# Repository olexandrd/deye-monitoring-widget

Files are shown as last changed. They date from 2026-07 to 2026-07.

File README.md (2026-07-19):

# ESP32-C3 Deye Local Monitor

Embedded MVP for an ESP32-C3 SuperMini USB-C with a 128x64 I2C OLED. It connects directly to a Deye/Solarman logger on the local Wi-Fi network and polls TCP port `8899` using a minimal Solarman V5 frame carrying a Modbus RTU read request.

No MQTT, Home Assistant, cloud service, RS485, CAN, SD card, RTC, or external gateway is used.

## Hardware

- ESP32-C3 SuperMini USB-C
- OLED 128x64 I2C display
- SSD1306 controller, usually address `0x3C`
- MH-CD42 Li-ion power bank / charger module
- 1-cell Li-ion/LiPo battery
- Wake button
- Voltage divider resistors: 680k and 470k

The `hardware/case/` directory contains a ready-to-print STL enclosure for the
ESP32-C3 SuperMini + OLED stack. The older 3D-model generation scripts are no
longer part of the repository; use the checked-in STL directly.

## Wiring

### OLED

ESP32-C3 SuperMini -> OLED SSD1306/SH1106 I2C

```text
3V3   -> VCC
GND   -> GND
GPIO3 -> SCL/SCK
GPIO4 -> SDA
```

Some OLED modules can use 5V VCC, but check your module before wiring. If your OLED does not work, scan the I2C bus and verify address `0x3C` or `0x3D`.

Many 1.3" OLED modules use SH1106 even when sold as SSD1306-compatible. Set `OLED_USE_SH1106` in `src/config.h` to switch between SSD1306 and SH1106. If the image is only clipped a few pixels on the left, keep SSD1306 and increase `OLED_UI_X_OFFSET`.

### ESP Supply Battery Measurement

Default ADC pin: `GPIO0`.

```text
Battery +  -> 680k -> GPIO0/ADC
GPIO0/ADC  -> 470k -> GND
Battery -  -> GND
```

This divider scales a 4.2V Li-ion battery to about 1.72V at the ADC pin:

```text
Vadc = Vbat * 470k / (680k + 470k)
```

Optional but recommended: add a 100nF capacitor from `GPIO0/ADC` to `GND` close to the ESP32-C3. The divider impedance is high, so the capacitor helps stabilize ADC readings. Never connect the battery positive directly to an ESP32 GPIO/ADC pin.

### Wake Options

Default mode relies on the MH-CD42 onboard or remote button. When MH-CD42 turns its 5V output off, the ESP32-C3 is unpowered; pressing the MH-CD42 button restores 5V and the ESP32-C3 cold-boots.

No ESP GPIO wake button is required in this mode:

```cpp
#define WAKE_BUTTON_ENABLED 0
```

Optional ESP deep-sleep wake button, only useful when MH-CD42 keeps 5V output enabled while the ESP32-C3 is sleeping:

```text
GPIO1 -> button -> GND
```

Enable it with:

```cpp
#define WAKE_BUTTON_ENABLED 1
#define WAKE_BUTTON_PIN 1
```

The firmware enables the internal pull-up. For more reliable deep-sleep wake, especially with long wires, add an external 100k pull-up from `GPIO1` to `3V3`. Do not pull the wake pin up to 5V.

On ESP32-C3, deep-sleep GPIO wake is available on `GPIO0..GPIO5`. Avoid `GPIO2`, `GPIO8`, and `GPIO9` for the wake button because they are boot strapping pins and can break boot/upload when held at the wrong level during reset.

### MH-CD42 KEY Keep-Alive

Some MH-CD42 boards turn off their 5V output when the load is too small. The module documentation describes `KEY` as a low-level trigger: briefly pulling `KEY` to `GND` simulates pressing the module button. The ESP32-C3 sends a short low pulse every 15 seconds so MH-CD42 keeps working while the firmware is awake.

Default: enabled on `GPIO5`.

```cpp
#define MH_CD42_KEEPALIVE_ENABLED 1
#define MH_CD42_KEEPALIVE_PIN 5
```

Timing:

```cpp
#define MH_CD42_KEEPALIVE_INTERVAL_MS 15000UL
#define MH_CD42_KEEPALIVE_PULSE_MS 250UL
```

Direct wiring is OK if the released `KEY` pin is measured at 3.3V or lower. If it is higher, use a small N-MOSFET or NPN transistor instead.

Direct wiring:

```text
ESP GPIO5 -> MH-CD42 KEY
ESP GND   -> MH-CD42 GND
```

Optional transistor wiring:

```text
ESP GPIO5 -> gate/base driver -> transistor
MH-CD42 KEY -> transistor drain/collector
MH-CD42 GND -> transistor source/emitter -> ESP GND
```

The GPIO is configured as open-drain: it only pulls `KEY` low for the pulse, then releases it. Do not drive the MH-CD42 `KEY` pin with 5V into an ESP GPIO.

Do not enable the ESP wake button and MH-CD42 keep-alive on the same GPIO at the same time.

### Power Chain

```text
Li-ion battery + -> MH-CD42 B+
Li-ion battery - -> MH-CD42 B-

MH-CD42 OUT+/5V -> ESP32-C3 5V/VBUS
MH-CD42 OUT-/GND -> ESP32-C3 GND

ESP32-C3 3V3 -> OLED VCC
ESP32-C3 GND -> OLED GND
ESP32-C3 GND -> battery divider GND
ESP32-C3 GND -> optional ESP wake button GND
ESP32-C3 GND -> optional MH-CD42 KEY keep-alive transistor GND
```

Keep all grounds common: MH-CD42 output ground, ESP32-C3 ground, OLED ground, resistor divider ground, and button ground.

## Configuration

Copy the example config and edit it:

```sh
cp src/config.example.h src/config.h
```

Set:

- `WIFI_SSID`
- `WIFI_PASSWORD`
- `DEYE_LOGGER_IP`
- `DEYE_LOGGER_SERIAL`
- `BLE_SETUP_ENABLED`, `BLE_SETUP_DEVICE_NAME`, and `BLE_SETUP_HOLD_MS` if using BLE setup mode
- `OLED_SDA_PIN` and `OLED_SCL_PIN` if your ESP32-C3 SuperMini revision uses different pins
- `WAKE_BUTTON_ENABLED` and `WAKE_BUTTON_PIN` only if using a separate ESP GPIO wake button instead of the MH-CD42 button
- `MH_CD42_KEEPALIVE_ENABLED` and `MH_CD42_KEEPALIVE_PIN` for the periodic MH-CD42 `KEY` pulse
- `SUPPLY_BATTERY_ADC_PIN` if `GPIO0` is not available on your board
- `SUPPLY_BATTERY_EMPTY_MV` and `SUPPLY_BATTERY_FULL_MV` to calibrate the displayed power battery percentage

`src/config.h` is ignored by git so Wi-Fi credentials are not committed.
Setting `BLE_SETUP_ENABLED` to `0` also excludes the BLE implementation and its
framework library from the linked firmware.

On boot, the firmware first loads runtime settings from ESP32 NVS. If a value
has never been saved through BLE, the matching `src/config.h` value is used as
the default.

## BLE Setup Mode

BLE setup mode is entered from a long press on the ESP GPIO wake button, so it
requires `WAKE_BUTTON_ENABLED` to be set to `1` and a button wired to
`WAKE_BUTTON_PIN`. Hold that button for 5 seconds while the firmware is awake to
start BLE setup mode. The device advertises for 3 minutes using a Nordic
UART-compatible service:

```text
Service: 6E400001-B5A3-F393-E0A9-E50E24DCCA9E
RX/write: 6E400002-B5A3-F393-E0A9-E50E24DCCA9E
TX/notify: 6E400003-B5A3-F393-E0A9-E50E24DCCA9E
```

Use a generic BLE client such as nRF Connect or LightBlue, connect to
`BLE_SETUP_DEVICE_NAME`, subscribe to TX notifications, then write `start` to
RX as UTF-8 text. Until `start` is received, the firmware periodically sends
`WRITE start` notifications so generic clients can display the ready state.
The setup flow is text-based:

```text
SETUP v3
SSID?
PASS?
DEYE HOST?
DEYE SERIAL?
SAVE yes/no?
```

The firmware also sends `empty keeps old` at the start of the flow and a short
`CUR ...` line before prompts where a current value is useful. Send an empty
text value at any prompt to keep the current value. Single-write clients remain
compatible. Longer answers may be split across consecutive writes; append a
newline to the final fragment to complete the value immediately. Values such as
`start`, `?`, and `skip` are treated literally after the setup flow has started.
After `yes`, the firmware tests the Wi-Fi connection before saving. If Wi-Fi
connects within
`BLE_WIFI_TEST_TIMEOUT_MS`, the full configuration is atomically written to NVS
and reused after power loss. If the test or save fails, the old active
configuration stays in NVS.

## Build and Flash

Install PlatformIO, then run:

```sh
pio run
pio run --target upload
pio device monitor
```

Serial monitor baud rate is `115200`.

BLE support makes the firmware too large for the default partition layout on a
4MB ESP32-C3 board. `platformio.ini` uses `min_spiffs.csv`, which provides two
larger application slots and keeps OTA partitions available.

## License

This project is licensed under the Creative Commons
Attribution-NonCommercial 4.0 International Public License
(`CC-BY-NC-4.0`). Non-commercial use, sharing, and adaptation are allowed with
attribution. Commercial use requires separate written permission.

This non-commercial license is applied intentionally to the firmware,
documentation, and the case STL, even though Creative Commons recommends
software-specific licenses for software-only projects.

## Third-Party Notice

This is an unofficial project and is not affiliated with or endorsed by Deye,
Solarman, PlatformIO, Espressif, Arduino, or U8g2.

The repository license applies only to the original project files in this
repository. Third-party dependencies are distributed under their own licenses.
No vendor firmware, proprietary documentation, credentials, or cloud service
materials are included.

## Fake Data Mode

For early display and wiring tests, set:

```cpp
#define USE_FAKE_DATA 1
```

The ESP32 still connects to Wi-Fi, but it does not contact the Deye logger. It generates changing SOC, battery, load, PV, and grid values and refreshes them using the `POLL_INTERVAL_MS` scheduler.

## Deye Direct Mode

For direct logger polling, set:

```cpp
#define USE_FAKE_DATA 0
```

The firmware connects to:

```text
DEYE_LOGGER_IP:8899
```

It sends a Solarman V5 local TCP frame containing a Modbus RTU read-holding-registers request. Polling is scheduled with `millis()` and defaults to once every 60 seconds.

The register map is isolated in `src/deye_client.h` under `namespace DeyeRegisters`. Register addresses and scaling may need adjustment for your exact inverter/logger firmware.
Daily generation is read from register `108` and displayed as daily energy (`Wh`/`kWh`).

## OLED UI

The main screen shows:

```text
SOC 65%   53.3V
BAT -120W 4.8 kWh
LOAD 430W PWR 86%
PV 820W
GRID 0W
OK 23s ago
```

States include boot, Wi-Fi connecting, Wi-Fi error, BLE setup, Deye polling, OK, stale, and Deye error. On failures, the display keeps the last valid metrics when available.

The screen starts at 50% OLED contrast, dims to 20% after 3 minutes, and enters ESP32 deep sleep after 10 minutes. In the default MH-CD42 mode, press the MH-CD42 onboard or remote button to restore 5V power and boot the ESP32-C3 again. If `WAKE_BUTTON_ENABLED` is set to `1`, pressing the ESP GPIO wake button while the device is awake restores the 50% display level and restarts the 3/10 minute timers.

## Serial Debug

USB Serial logs:

- boot info
- Wi-Fi status
- ESP32 IP
- Deye logger IP and port
- poll start
- poll success/failure
- raw response length
- parsed metrics
- error codes

The Wi-Fi password is never printed.

## Known Limitations

- The Solarman V5 implementation is intentionally minimal and built for local TCP polling.
- Deye register addresses are model-dependent and marked for verification.
- Only a single holding-register range is read in the MVP.
- No NTP is used, so the display shows data age instead of wall-clock time.
- Supply battery percentage uses a configurable linear Li-ion voltage mapping, not a fuel-gauge IC.

## TODO

- Verify register addresses and scaling for the target Deye inverter model.
- Add an optional I2C scanner helper.
- Add a button to switch pages.
- Add NTP time.
- Add a web status page.
- Add OTA firmware update.
- Add W25Q64 binary ring buffer.
- Add CSV export over HTTP.
- Add multiple OLED pages.
- Add GC9A01 TFT version.

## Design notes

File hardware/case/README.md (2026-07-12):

# ESP32-C3 SuperMini + OLED case

Ready-to-print enclosure for the stacked module:

- ESP32-C3 SuperMini mounted behind the OLED on pin headers
- 0.96" I2C OLED module with four corner holes
- front display window
- side USB-C cutout
- single STL model

## Files

- `oled-esp.stl` - ready-to-print STL model

## Print Notes

The STL is exported from the latest local case design. Import `oled-esp.stl`
directly into your slicer and verify the following dimensions against your
actual boards before printing:

- OLED module: `33.7 x 35.5 mm`
- OLED screen/window: `23 x 34.5 mm`
- ESP32-C3 SuperMini: `17.9 x 22.9 mm`
- OLED-to-ESP gap: `7.3 mm`
- USB distance from ESP board edge to connector center: `8.4 mm`

If the fit is tight, tune the original CAD model outside this repository and
replace `oled-esp.stl` with a newly exported version.

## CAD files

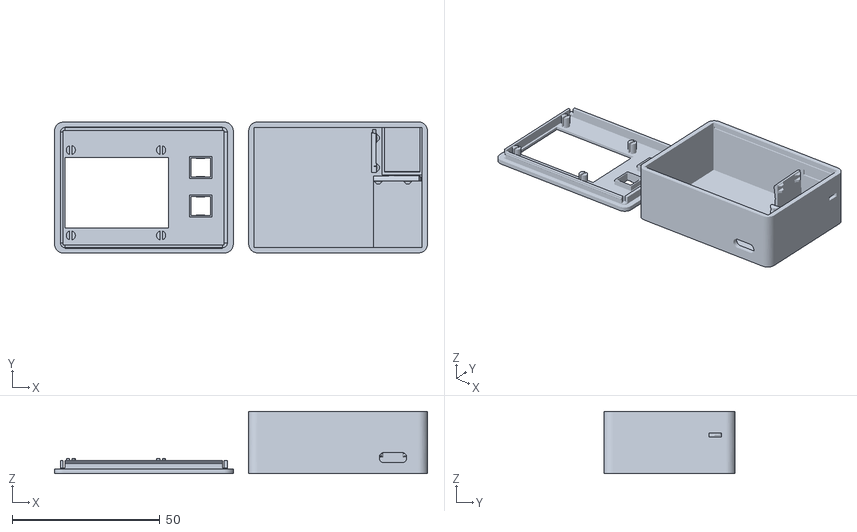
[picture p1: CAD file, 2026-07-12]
hardware/case/oled-esp.stl
126.2 x 44.3 x 21.0

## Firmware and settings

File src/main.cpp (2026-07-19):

#include <Arduino.h>
#include <WiFi.h>
#include <driver/gpio.h>
#include <esp_sleep.h>

#include "config.h"
#ifndef BLE_SETUP_ENABLED
#define BLE_SETUP_ENABLED 1
#endif
#if BLE_SETUP_ENABLED
#include "ble_setup.h"
#endif
#include "deye_client.h"
#include "display.h"
#include "metrics.h"
#include "runtime_config.h"

#ifndef DISPLAY_BRIGHTNESS_HIGH_PERCENT
#define DISPLAY_BRIGHTNESS_HIGH_PERCENT 50
#endif
#ifndef DISPLAY_BRIGHTNESS_DIM_PERCENT
#define DISPLAY_BRIGHTNESS_DIM_PERCENT 20
#endif
#ifndef DISPLAY_DIM_AFTER_MS
#define DISPLAY_DIM_AFTER_MS 180000UL
#endif
#ifndef DISPLAY_SLEEP_AFTER_MS
#define DISPLAY_SLEEP_AFTER_MS 600000UL
#endif

#ifndef WAKE_BUTTON_ENABLED
#define WAKE_BUTTON_ENABLED 0
#endif
#ifndef WAKE_BUTTON_PIN
#define WAKE_BUTTON_PIN 1
#endif
#ifndef WAKE_BUTTON_ACTIVE_LOW
#define WAKE_BUTTON_ACTIVE_LOW 1
#endif
#ifndef WAKE_BUTTON_DEBOUNCE_MS
#define WAKE_BUTTON_DEBOUNCE_MS 50
#endif
#ifndef BLE_SETUP_HOLD_MS
#define BLE_SETUP_HOLD_MS 5000UL
#endif
#ifndef BLE_WIFI_TEST_TIMEOUT_MS
#define BLE_WIFI_TEST_TIMEOUT_MS 20000UL
#endif

#ifndef MH_CD42_KEEPALIVE_ENABLED
#define MH_CD42_KEEPALIVE_ENABLED 1
#endif
#ifndef MH_CD42_KEEPALIVE_PIN
#define MH_CD42_KEEPALIVE_PIN 5
#endif
#ifndef MH_CD42_KEEPALIVE_INTERVAL_MS
#define MH_CD42_KEEPALIVE_INTERVAL_MS 15000UL
#endif
#ifndef MH_CD42_KEEPALIVE_PULSE_MS
#define MH_CD42_KEEPALIVE_PULSE_MS 250UL
#endif

#ifndef SUPPLY_BATTERY_ADC_ENABLED
#define SUPPLY_BATTERY_ADC_ENABLED 1
#endif
#ifndef SUPPLY_BATTERY_ADC_PIN
#define SUPPLY_BATTERY_ADC_PIN 0
#endif
#ifndef SUPPLY_BATTERY_R_TOP_OHMS
#define SUPPLY_BATTERY_R_TOP_OHMS 680000.0f
#endif
#ifndef SUPPLY_BATTERY_R_BOTTOM_OHMS
#define SUPPLY_BATTERY_R_BOTTOM_OHMS 470000.0f
#endif
#ifndef SUPPLY_BATTERY_EMPTY_MV
#define SUPPLY_BATTERY_EMPTY_MV 3200.0f
#endif
#ifndef SUPPLY_BATTERY_FULL_MV
#define SUPPLY_BATTERY_FULL_MV 4200.0f
#endif
#ifndef SUPPLY_BATTERY_SAMPLE_COUNT
#define SUPPLY_BATTERY_SAMPLE_COUNT 16
#endif
#ifndef SUPPLY_BATTERY_READ_INTERVAL_MS
#define SUPPLY_BATTERY_READ_INTERVAL_MS 30000UL
#endif

namespace {
constexpr uint32_t WiFiRetryMinMs = 5000;
constexpr uint32_t WiFiRetryMaxMs = 30000;

InverterMetrics metrics;
RuntimeConfig runtimeConfig;
#if BLE_SETUP_ENABLED
RuntimeConfig pendingBleConfig;
#endif
DeyeClient deyeClient(
    DEYE_LOGGER_IP,
    DEYE_LOGGER_PORT,
    DEYE_LOGGER_SERIAL,
    DEYE_MODBUS_SLAVE_ID
);
#if BLE_SETUP_ENABLED
BleSetupMode bleSetup;
#endif

SupplyBatteryStatus supplyBattery = {false, NAN, 0};
AppState appState = AppState::Boot;
uint32_t nextPollMs = 0;
uint32_t nextWiFiRetryMs = 0;
uint32_t wifiRetryDelayMs = WiFiRetryMinMs;
bool wasWifiConnected = false;
uint32_t lastUserActivityMs = 0;
uint32_t nextSupplyBatteryReadMs = 0;
bool displayDimmed = false;
bool wakeButtonStablePressed = false;
bool wakeButtonLastRawPressed = false;
uint32_t wakeButtonRawChangedMs = 0;
uint32_t wakeButtonPressedStartedMs = 0;
bool wakeButtonLongPressHandled = false;
uint32_t nextMhCd42KeepAliveMs = 0;
uint32_t mhCd42KeepAlivePulseStartedMs = 0;
bool mhCd42KeepAlivePulseActive = false;
#if BLE_SETUP_ENABLED
bool wifiConfigTestActive = false;
uint32_t wifiConfigTestDeadlineMs = 0;
#endif

void showState(AppState state, const char* detail = nullptr) {
    appState = state;
    displayStatus(appState, metrics, detail, supplyBattery);
}

void applyDeyeRuntimeConfig() {
    deyeClient.configure(
        runtimeConfig.deyeHost,
        DEYE_LOGGER_PORT,
        runtimeConfig.deyeSerial,
        DEYE_MODBUS_SLAVE_ID
    );
}

float clampFloat(float value, float minValue, float maxValue) {
    if (value < minValue) {
        return minValue;
    }
    if (value > maxValue) {
        return maxValue;
    }
    return value;
}

bool wakeButtonPressed() {
#if WAKE_BUTTON_ENABLED
    const int level = digitalRead(WAKE_BUTTON_PIN);
#if WAKE_BUTTON_ACTIVE_LOW
    return level == LOW;
#else
    return level == HIGH;
#endif
#else
    return false;
#endif
}

void setupWakeButton() {
#if WAKE_BUTTON_ENABLED
#if WAKE_BUTTON_ACTIVE_LOW
    pinMode(WAKE_BUTTON_PIN, INPUT_PULLUP);
#else
    pinMode(WAKE_BUTTON_PIN, INPUT_PULLDOWN);
#endif
    wakeButtonStablePressed = wakeButtonPressed();
    wakeButtonLastRawPressed = wakeButtonStablePressed;
#endif
}

void setupSupplyBatteryMonitor() {
#if SUPPLY_BATTERY_ADC_ENABLED
    analogReadResolution(12);
    analogSetPinAttenuation(SUPPLY_BATTERY_ADC_PIN, ADC_11db);
#endif
}

void updateSupplyBattery(uint32_t nowMs, bool force = false) {
#if SUPPLY_BATTERY_ADC_ENABLED
    if (!force && nowMs < nextSupplyBatteryReadMs) {
        return;
    }

    uint16_t sampleCount = SUPPLY_BATTERY_SAMPLE_COUNT;
    if (sampleCount == 0) {
        sampleCount = 1;
    }

    uint32_t adcMilliVoltsTotal = 0;
    for (uint16_t i = 0; i < sampleCount; ++i) {
        adcMilliVoltsTotal += analogReadMilliVolts(SUPPLY_BATTERY_ADC_PIN);
        delay(2);
    }

    const float adcMilliVolts = static_cast<float>(adcMilliVoltsTotal) / sampleCount;
    const float dividerRatio =
        (SUPPLY_BATTERY_R_TOP_OHMS + SUPPLY_BATTERY_R_BOTTOM_OHMS) / SUPPLY_BATTERY_R_BOTTOM_OHMS;
    const float batteryMilliVolts = adcMilliVolts * dividerRatio;
    const float rawPercent =
        ((batteryMilliVolts - SUPPLY_BATTERY_EMPTY_MV) /
         (SUPPLY_BATTERY_FULL_MV - SUPPLY_BATTERY_EMPTY_MV)) *
        100.0f;

    supplyBattery.valid = true;
    supplyBattery.voltage = batteryMilliVolts / 1000.0f;
    supplyBattery.chargePercent = static_cast<uint8_t>(clampFloat(rawPercent, 0.0f, 100.0f) + 0.5f);
    nextSupplyBatteryReadMs = nowMs + SUPPLY_BATTERY_READ_INTERVAL_MS;

    Serial.printf(
        "Supply battery: ADC=%.0fmV BAT=%.2fV CHG=%u%%\n",
        adcMilliVolts,
        supplyBattery.voltage,
        supplyBattery.chargePercent
    );
#else
    supplyBattery.valid = false;
    supplyBattery.voltage = NAN;
    supplyBattery.chargePercent = 0;
#endif
}

void markUserActivity(uint32_t nowMs) {
    lastUserActivityMs = nowMs;
    nextPollMs = nowMs;
    displayWake();
    displaySetBrightnessPercent(DISPLAY_BRIGHTNESS_HIGH_PERCENT);
    displayStatus(appState, metrics, nullptr, supplyBattery);

    if (displayDimmed) {
        displayDimmed = false;
        Serial.println("Display brightness restored by button");
    } else {
        Serial.println("User activity timer reset by button");
    }
    Serial.println("Deye poll requested by wake button");
}

void startBleSetup(uint32_t nowMs) {
#if BLE_SETUP_ENABLED
    markUserActivity(nowMs);
    showState(AppState::BleSetup, "setup");
    bleSetup.begin(runtimeConfig, nowMs);
#else
    (void)nowMs;
    Serial.println("BLE setup disabled");
#endif
}

void handleWakeButton(uint32_t nowMs) {
#if WAKE_BUTTON_ENABLED
    const bool rawPressed = wakeButtonPressed();
    if (rawPressed != wakeButtonLastRawPressed) {
        wakeButtonLastRawPressed = rawPressed;
        wakeButtonRawChangedMs = nowMs;
    }

    if (nowMs - wakeButtonRawChangedMs < WAKE_BUTTON_DEBOUNCE_MS) {
        return;
    }

    if (wakeButtonStablePressed != rawPressed) {
        wakeButtonStablePressed = rawPressed;
        if (wakeButtonStablePressed) {
            Serial.println("Wake button pressed");
            wakeButtonPressedStartedMs = nowMs;
            wakeButtonLongPressHandled = false;
            markUserActivity(nowMs);
        } else {
            wakeButtonPressedStartedMs = 0;
            wakeButtonLongPressHandled = false;
        }
    }

#if BLE_SETUP_ENABLED
    if (wakeButtonStablePressed && !wakeButtonLongPressHandled &&
        nowMs - wakeButtonPressedStartedMs >= BLE_SETUP_HOLD_MS) {
        wakeButtonLongPressHandled = true;
        Serial.println("Wake button long press: starting BLE setup");
        startBleSetup(nowMs);
    }
#endif
#endif
}

void configureWakeButtonForDeepSleep() {
#if WAKE_BUTTON_ENABLED
    const gpio_num_t pin = static_cast<gpio_num_t>(WAKE_BUTTON_PIN);
#if WAKE_BUTTON_ACTIVE_LOW
    gpio_pullup_en(pin);
    gpio_pulldown_dis(pin);
    esp_deep_sleep_enable_gpio_wakeup(1ULL << WAKE_BUTTON_PIN, ESP_GPIO_WAKEUP_GPIO_LOW);
#else
    gpio_pulldown_en(pin);
    gpio_pullup_dis(pin);
    esp_deep_sleep_enable_gpio_wakeup(1ULL << WAKE_BUTTON_PIN, ESP_GPIO_WAKEUP_GPIO_HIGH);
#endif
#else
    Serial.println("ESP GPIO wake disabled; wake by reset, power cycle, or MH-CD42 button");
#endif
}

void releaseMhCd42KeepAlivePin() {
#if MH_CD42_KEEPALIVE_ENABLED
    gpio_set_level(static_cast<gpio_num_t>(MH_CD42_KEEPALIVE_PIN), 1);
    mhCd42KeepAlivePulseActive = false;
#endif
}

void setupMhCd42KeepAlive(uint32_t nowMs) {
#if MH_CD42_KEEPALIVE_ENABLED
    const gpio_num_t pin = static_cast<gpio_num_t>(MH_CD42_KEEPALIVE_PIN);
    gpio_set_direction(pin, GPIO_MODE_OUTPUT_OD);
    gpio_set_level(pin, 1);
    nextMhCd42KeepAliveMs = nowMs + MH_CD42_KEEPALIVE_INTERVAL_MS;
#endif
}

void handleMhCd42KeepAlive(uint32_t nowMs) {
#if MH_CD42_KEEPALIVE_ENABLED
    const gpio_num_t pin = static_cast<gpio_num_t>(MH_CD42_KEEPALIVE_PIN);

    if (mhCd42KeepAlivePulseActive) {
        if (nowMs - mhCd42KeepAlivePulseStartedMs >= MH_CD42_KEEPALIVE_PULSE_MS) {
            gpio_set_level(pin, 1);
            mhCd42KeepAlivePulseActive = false;
            nextMhCd42KeepAliveMs = nowMs + MH_CD42_KEEPALIVE_INTERVAL_MS;
            Serial.println("MH-CD42 KEY released");
        }
        return;
    }

    if (nowMs >= nextMhCd42KeepAliveMs) {
        gpio_set_level(pin, 0);
        mhCd42KeepAlivePulseStartedMs = nowMs;
        mhCd42KeepAlivePulseActive = true;
        Serial.println("MH-CD42 KEY keep-alive pulse");
    }
#endif
}

void enterDeepSleep(uint32_t nowMs) {
    Serial.printf("Entering deep sleep after %lu ms of activity\n", static_cast<unsigned long>(nowMs - lastUserActivityMs));
    showState(AppState::Stale, "sleep");
    delay(250);

    releaseMhCd42KeepAlivePin();
#if BLE_SETUP_ENABLED
    bleSetup.stop();
#endif
    displaySleep();
    WiFi.disconnect(true);
    WiFi.mode(WIFI_OFF);
    configureWakeButtonForDeepSleep();
    Serial.flush();
    esp_deep_sleep_start();
}

void handleDisplayPower(uint32_t nowMs) {
    const uint32_t activeMs = nowMs - lastUserActivityMs;

    if (activeMs >= DISPLAY_SLEEP_AFTER_MS) {
        enterDeepSleep(nowMs);
        return;
    }

    if (!displayDimmed && activeMs >= DISPLAY_DIM_AFTER_MS) {
        displaySetBrightnessPercent(DISPLAY_BRIGHTNESS_DIM_PERCENT);
        displayDimmed = true;
        Serial.printf("Display brightness dimmed to %u%%\n", DISPLAY_BRIGHTNESS_DIM_PERCENT);
    }
}

void startWiFiConnect(uint32_t nowMs, const RuntimeConfig& config, const char* detail = "connect") {
    Serial.printf("WiFi connecting to SSID: %s\n", config.wifiSsid);
    WiFi.mode(WIFI_STA);
    WiFi.disconnect(false);
    WiFi.begin(config.wifiSsid, config.wifiPassword);
    nextWiFiRetryMs = nowMs + wifiRetryDelayMs;
    showState(AppState::WiFiConnecting, detail);
}

void startWiFiConnect(uint32_t nowMs) {
    startWiFiConnect(nowMs, runtimeConfig);
}

#if BLE_SETUP_ENABLED
void startBleWiFiConfigTest(uint32_t nowMs, const RuntimeConfig& config) {
    pendingBleConfig = config;
    wifiConfigTestActive = true;
    wifiConfigTestDeadlineMs = nowMs + BLE_WIFI_TEST_TIMEOUT_MS;
    wasWifiConnected = false;

    WiFi.mode(WIFI_STA);
    WiFi.disconnect(false);
    delay(100);
    WiFi.begin(pendingBleConfig.wifiSsid, pendingBleConfig.wifiPassword);

    showState(AppState::WiFiConnecting, "test");
    bleSetup.notifyWifiTestStarted();
    Serial.printf("BLE setup: testing WiFi SSID %s\n", pendingBleConfig.wifiSsid);
}

bool handleBleWiFiConfigTest(uint32_t nowMs) {
    if (!wifiConfigTestActive) {
        return false;
    }

    const wl_status_t status = WiFi.status();
    if (status == WL_CONNECTED) {
        const String ip = WiFi.localIP().toString();
        if (runtimeConfigSave(pendingBleConfig)) {
            runtimeConfig = pendingBleConfig;
            applyDeyeRuntimeConfig();
            wifiConfigTestActive = false;
            wasWifiConnected = true;
            wifiRetryDelayMs = WiFiRetryMinMs;
            nextPollMs = nowMs;
            showState(AppState::Ok, ip.c_str());
            bleSetup.notifyWifiTestResult(true, ip.c_str());
            Serial.print("BLE setup: WiFi test OK, ESP32 IP: ");
            Serial.println(ip);
        } else {
            wifiConfigTestActive = false;
            showState(AppState::WiFiError, "NVS");
            bleSetup.notifyWifiTestResult(false, "NVS save failed");
            startWiFiConnect(nowMs);
        }
        return true;
    }

    if (status == WL_CONNECT_FAILED || nowMs >= wifiConfigTestDeadlineMs) {
        wifiConfigTestActive = false;
        wasWifiConnected = false;
        showState(AppState::WiFiError, "test");
        bleSetup.notifyWifiTestResult(false, "cannot connect");
        Serial.println("BLE setup: WiFi test failed; reverting active config");
        startWiFiConnect(nowMs);
        return true;
    }

    showState(AppState::WiFiConnecting, "test");
    return true;
}
#endif

void handleWiFi(uint32_t nowMs) {
    const wl_status_t status = WiFi.status();
    const bool connected = status == WL_CONNECTED;

    if (connected) {
        if (!wasWifiConnected) {
            wasWifiConnected = true;
            wifiRetryDelayMs = WiFiRetryMinMs;
            Serial.print("WiFi connected, ESP32 IP: ");
            Serial.println(WiFi.localIP());
            showState(metrics.valid ? AppState::Stale : AppState::Ok, WiFi.localIP().toString().c_str());
            nextPollMs = nowMs;
        }
        return;
    }

    if (wasWifiConnected) {
        wasWifiConnected = false;
        Serial.println("WiFi disconnected");
        showState(AppState::WiFiError, "lost");
        nextWiFiRetryMs = nowMs + wifiRetryDelayMs;
    }

    if (nowMs >= nextWiFiRetryMs) {
        Serial.println("WiFi retry");
        WiFi.disconnect(false);
        WiFi.begin(runtimeConfig.wifiSsid, runtimeConfig.wifiPassword);
        showState(AppState::WiFiConnecting, "retry");
        nextWiFiRetryMs = nowMs + wifiRetryDelayMs;
        wifiRetryDelayMs = min(wifiRetryDelayMs * 2, WiFiRetryMaxMs);
    }
}

void pollDeye(uint32_t nowMs) {
    if (nowMs < nextPollMs) {
        return;
    }

    nextPollMs = nowMs + POLL_INTERVAL_MS;

#if USE_FAKE_DATA
    Serial.println("Fake data poll start");
    updateFakeMetrics(metrics, nowMs);
    Serial.printf(
        "Fake metrics: SOC=%.0f BAT_V=%.1f BAT_W=%.0f DAY=%.1fkWh LOAD=%.0f GRID=%.0f PV=%.0f\n",
        metrics.batterySoc,
        metrics.batteryVoltage,
        metrics.batteryPower,
        metrics.dailyGenerationKwh,
        metrics.loadPower,
        metrics.gridPower,
        metrics.pvTotalPower
    );
    showState(WiFi.status() == WL_CONNECTED ? AppState::Ok : AppState::WiFiError, "fake");
#else
    if (WiFi.status() != WL_CONNECTED) {
        showState(AppState::WiFiError, "retry");
        return;
    }

    showState(AppState::DeyePolling);
    if (deyeClient.poll(metrics)) {
        Serial.println("Deye poll success");
        showState(AppState::Ok);
    } else {
        metrics.errorCode = -1;
        Serial.printf("Deye poll failed: %s\n", deyeClient.lastError());
        showState(metrics.valid ? AppState::Stale : AppState::DeyeError, deyeClient.lastError());
    }
#endif
}
}

void setup() {
    Serial.begin(115200);
    delay(100);

    WiFi.persistent(false);
    runtimeConfigLoad(runtimeConfig);
    applyDeyeRuntimeConfig();
    setupWakeButton();
    setupSupplyBatteryMonitor();
    resetMetrics(metrics);
    displayBegin();
    displaySetBrightnessPercent(DISPLAY_BRIGHTNESS_HIGH_PERCENT);
    lastUserActivityMs = millis();
    wakeButtonRawChangedMs = lastUserActivityMs;
    setupMhCd42KeepAlive(lastUserActivityMs);
    updateSupplyBattery(lastUserActivityMs, true);
    showState(AppState::Boot);

    Serial.println();
    Serial.println("ESP32-C3 Deye Local Monitor boot");
    Serial.printf("Wakeup cause: %d\n", static_cast<int>(esp_sleep_get_wakeup_cause()));
    runtimeConfigPrint(runtimeConfig);
    Serial.printf("OLED SDA=%d SCL=%d address=0x%02X\n", OLED_SDA_PIN, OLED_SCL_PIN, OLED_I2C_ADDRESS);
    Serial.printf("Display brightness: %u%% -> %u%% after %lu ms, sleep after %lu ms\n",
        DISPLAY_BRIGHTNESS_HIGH_PERCENT,
        DISPLAY_BRIGHTNESS_DIM_PERCENT,
        static_cast<unsigned long>(DISPLAY_DIM_AFTER_MS),
        static_cast<unsigned long>(DISPLAY_SLEEP_AFTER_MS)
    );
#if WAKE_BUTTON_ENABLED
    Serial.printf("Wake button GPIO=%d active=%s\n", WAKE_BUTTON_PIN, WAKE_BUTTON_ACTIVE_LOW ? "LOW" : "HIGH");
    Serial.printf("BLE setup long press: %s, hold %lu ms\n",
        BLE_SETUP_ENABLED ? "enabled" : "disabled",
        static_cast<unsigned long>(BLE_SETUP_HOLD_MS)
    );
#else
    Serial.println("Wake button GPIO disabled; relying on reset/power-cycle/MH-CD42 button");
#endif
#if MH_CD42_KEEPALIVE_ENABLED
    Serial.printf(
        "MH-CD42 keep-alive GPIO=%d pulse=%lu ms interval=%lu ms\n",
        MH_CD42_KEEPALIVE_PIN,
        static_cast<unsigned long>(MH_CD42_KEEPALIVE_PULSE_MS),
        static_cast<unsigned long>(MH_CD42_KEEPALIVE_INTERVAL_MS)
    );
#else
    Serial.println("MH-CD42 keep-alive disabled");
#endif
#if SUPPLY_BATTERY_ADC_ENABLED
    Serial.printf(
        "Supply battery ADC GPIO=%d divider %.0f/%.0f ohm\n",
        SUPPLY_BATTERY_ADC_PIN,
        SUPPLY_BATTERY_R_TOP_OHMS,
        SUPPLY_BATTERY_R_BOTTOM_OHMS
    );
#endif
    Serial.printf("Poll interval: %lu ms\n", static_cast<unsigned long>(POLL_INTERVAL_MS));
    Serial.printf("Fake data mode: %s\n", USE_FAKE_DATA ? "on" : "off");

    startWiFiConnect(millis());
}

void loop() {
    const uint32_t nowMs = millis();
    handleWakeButton(nowMs);
    handleMhCd42KeepAlive(nowMs);
#if BLE_SETUP_ENABLED
    bleSetup.handle(nowMs);
#endif
    updateSupplyBattery(nowMs);
    handleDisplayPower(nowMs);

#if BLE_SETUP_ENABLED
    RuntimeConfig requestedConfig;
    if (bleSetup.takeSaveRequest(requestedConfig)) {
        startBleWiFiConfigTest(nowMs, requestedConfig);
    }

    if (handleBleWiFiConfigTest(nowMs)) {
        yield();
        return;
    }
#endif

    handleWiFi(nowMs);

#if BLE_SETUP_ENABLED
    if (bleSetup.active()) {
        yield();
        return;
    }
#endif

#if USE_FAKE_DATA
    pollDeye(nowMs);
#else
    if (WiFi.status() == WL_CONNECTED) {
        pollDeye(nowMs);
    }
#endif

    static uint32_t nextDisplayRefreshMs = 0;
    if (nowMs >= nextDisplayRefreshMs) {
        nextDisplayRefreshMs = nowMs + 1000;
        if (appState == AppState::Ok && metrics.valid && nowMs - metrics.timestampMs > POLL_INTERVAL_MS + 5000UL) {
            showState(AppState::Stale);
        } else {
            displayStatus(appState, metrics, nullptr, supplyBattery);
        }
    }

    yield();
}

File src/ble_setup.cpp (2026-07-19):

#include "config.h"

#ifndef BLE_SETUP_ENABLED
#define BLE_SETUP_ENABLED 1
#endif

#if BLE_SETUP_ENABLED

#include "ble_setup.h"

#include <string.h>
#include <string>

#include <BLE2902.h>
#include <BLEDevice.h>
#include <BLEServer.h>
#include <BLEUtils.h>

#ifndef BLE_SETUP_DEVICE_NAME
#define BLE_SETUP_DEVICE_NAME "Deye Monitor"
#endif
#ifndef BLE_SETUP_WINDOW_MS
#define BLE_SETUP_WINDOW_MS 180000UL
#endif

namespace {
constexpr const char* ServiceUuid = "6E400001-B5A3-F393-E0A9-E50E24DCCA9E";
constexpr const char* RxUuid = "6E400002-B5A3-F393-E0A9-E50E24DCCA9E";
constexpr const char* TxUuid = "6E400003-B5A3-F393-E0A9-E50E24DCCA9E";
constexpr size_t NotifyChunkLen = 18;
constexpr const char* ReadyText = "WRITE start\r\n";
constexpr uint32_t ReadyReminderMs = 2000UL;
constexpr uint32_t RxWriteIdleMs = 250UL;

BleSetupMode* activeSetup = nullptr;
BLEServer* bleServer = nullptr;
BLECharacteristic* txCharacteristic = nullptr;

class SetupServerCallbacks : public BLEServerCallbacks {
public:
    void onConnect(BLEServer*) override {
        if (activeSetup != nullptr) {
            activeSetup->handleClientConnected();
        }
    }

    void onDisconnect(BLEServer*) override {
        if (activeSetup != nullptr) {
            activeSetup->handleClientDisconnected();
        }
    }
};

class SetupRxCallbacks : public BLECharacteristicCallbacks {
public:
    void onWrite(BLECharacteristic* characteristic) override {
        if (activeSetup == nullptr || characteristic == nullptr) {
            return;
        }

        const std::string value = characteristic->getValue();
        activeSetup->handleRxWrite(
            reinterpret_cast<const uint8_t*>(value.data()),
            value.length()
        );
    }
};

String cleanedInput(const String& value) {
    String input = value;
    input.trim();
    return input;
}
}

void BleSetupMode::begin(const RuntimeConfig& currentConfig, uint32_t nowMs) {
    if (_active) {
        _deadlineMs = nowMs + BLE_SETUP_WINDOW_MS;
        sendText("\r\nEXTENDED\r\n");
        sendPrompt();
        return;
    }

    _sessionConfig = currentConfig;
    _saveConfig = {};
    _stage = Stage::Ready;
    _active = true;
    _connected = false;
    _savePending = false;
    _deadlineMs = nowMs + BLE_SETUP_WINDOW_MS;
    _stopAtMs = 0;
    _nextPromptReminderMs = 0;
    _promptReminderCount = 0;
    resetRxInput();

    startBle();
    Serial.println("BLE setup: advertising started for 3 minutes");
}

void BleSetupMode::handle(uint32_t nowMs) {
    if (!_active) {
        return;
    }

    processRxInput(nowMs);

    if (_stopAtMs != 0 && nowMs >= _stopAtMs) {
        stop();
        return;
    }

    if (nowMs >= _deadlineMs) {
        sendText("\r\nBLE setup timeout.\r\n");
        stop();
        return;
    }

    if (_connected && _stage == Stage::Ready && nowMs >= _nextPromptReminderMs) {
        sendText(ReadyText);
        _nextPromptReminderMs = nowMs + ReadyReminderMs;
        return;
    }

    if (_connected && _nextPromptReminderMs != 0 && nowMs >= _nextPromptReminderMs) {
        sendText("\r\n");
        sendPrompt();
        ++_promptReminderCount;
        _nextPromptReminderMs = nowMs + 3000UL;
    }
}

void BleSetupMode::stop() {
    if (!_active && bleServer == nullptr) {
        return;
    }

    Serial.println("BLE setup: stopped");
    BLEDevice::stopAdvertising();
    if (bleServer != nullptr && bleServer->getConnectedCount() > 0) {
        bleServer->disconnect(bleServer->getConnId());
    }
    setTxValue(ReadyText);
    activeSetup = nullptr;
    _active = false;
    _connected = false;
    _stage = Stage::Idle;
    _stopAtMs = 0;
    _nextPromptReminderMs = 0;
    _promptReminderCount = 0;
    resetRxInput();
}

bool BleSetupMode::active() const {
    return _active;
}

bool BleSetupMode::takeSaveRequest(RuntimeConfig& outConfig) {
    if (!_savePending) {
        return false;
    }

    outConfig = _saveConfig;
    _savePending = false;
    return true;
}

void BleSetupMode::notifyWifiTestStarted() {
    _stage = Stage::WaitingForWiFiTest;
    sendText("\r\nWIFI TEST\r\n");
}

void BleSetupMode::notifyWifiTestResult(bool ok, const char* detail) {
    if (ok) {
        _stage = Stage::Done;
        sendText("\r\nWIFI OK\r\n");
        if (detail != nullptr && detail[0] != '\0') {
            sendText(String("IP ") + detail + "\r\n");
        }
        sendText("SAVED\r\n");
        scheduleStop(1200);
        return;
    }

    _stage = Stage::WiFiSsid;
    sendText("\r\nWIFI FAIL\r\n");
    if (detail != nullptr && detail[0] != '\0') {
        sendText(String("ERR ") + detail + "\r\n");
    }
    sendText("NOT SAVED\r\n");
    if (!_connected) {
        scheduleStop(500);
        return;
    }
    sendPrompt();
}

void BleSetupMode::handleClientConnected() {
    _connected = true;
    Serial.println("BLE setup: client connected");
    setTxValue(ReadyText);
    _stage = Stage::Ready;
    _nextPromptReminderMs = millis() + ReadyReminderMs;
    _promptReminderCount = 0;
}

void BleSetupMode::handleClientDisconnected() {
    _connected = false;
    Serial.println("BLE setup: client disconnected");
    _nextPromptReminderMs = 0;
    if (_active && _stage != Stage::WaitingForWiFiTest && _stage != Stage::Done) {
        BLEDevice::startAdvertising();
    }
}

void BleSetupMode::handleRxWrite(const uint8_t* data, size_t len) {
    if (!_active) {
        return;
    }

    portENTER_CRITICAL(&_rxMux);
    if (!_rxLineReady) {
        if (len == 0) {
            _rxLineReady = true;
        } else {
            for (size_t i = 0; i < len; ++i) {
                const char value = static_cast<char>(data[i]);
                if (value == '\r' || value == '\n') {
                    _rxLineReady = true;
                    break;
                }
                if (_rxLength < sizeof(_rxBuffer) - 1) {
                    _rxBuffer[_rxLength++] = value;
                } else {
                    _rxOverflow = true;
                }
            }
        }
        _rxLastWriteMs = millis();
    }
    portEXIT_CRITICAL(&_rxMux);
}
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

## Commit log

2026-07-12 Initial GitHub-ready project
    [oled-esp.stl]
2026-07-19 Document BLE setup flow and wake button requirements
